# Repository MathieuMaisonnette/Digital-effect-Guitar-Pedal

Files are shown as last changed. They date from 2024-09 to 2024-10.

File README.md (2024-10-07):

# Guitar Effects Pedal - Capacitive Sensor Project

<div align="center">
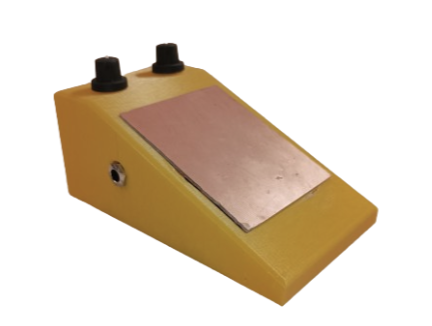
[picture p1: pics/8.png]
finished product
    
</div>

This project focuses on the development of a multi-effects pedal for electric guitars. The pedal integrates a capacitive sensor to manipulate audio effects in real time based on the proximity of the user’s foot to a capacitive plate. This is built using the STM32 microcontroller and includes various iconic guitar effects such as tremolo, fuzz, and overdrive.

**The following explanation is only a summarized version of the project. For more details, feel free to consult the report (in French), which explains the operation of each subcomponent in more detail.**

## Features
- **Capacitive Sensor**: The pedal uses a capacitive plate to adjust effect parameters without physical contact, offering a unique and dynamic user interface.
- **Multi-effects**: The pedal supports a range of effects like fuzz, tremolo, and overdrive, with more effects easily implementable through software updates.
- **STM32 Microcontroller**: A STM32F303-K8 microcontroller is responsible for audio signal processing and handling the effects.
- **Custom PCB and 3D Printed Case**: Designed for compactness and ease of use, the pedal features a custom-printed circuit board (PCB) and a 3D-printed case modeled after well-known pedal designs.

## Hardware Overview
- **Capacitive Sensor**: Detects foot proximity to control effects in real time.

<div align="center">
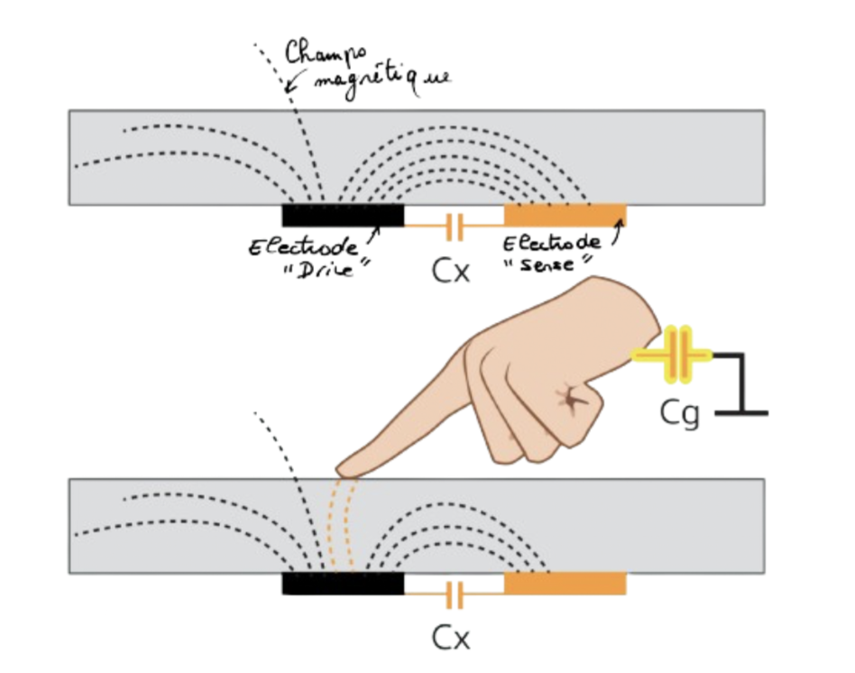
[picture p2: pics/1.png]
    
    <p><em>Figure 1: Operation of the capacitive sensor.</em></p>
</div>

- **STM32F303-K8**: The microcontroller that manages signal processing and control.

<div align="center">
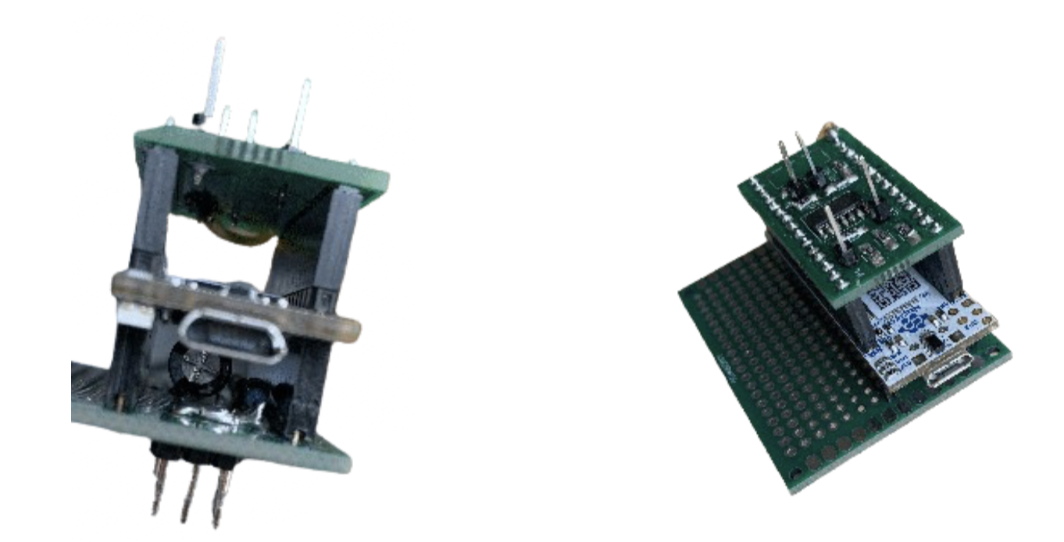
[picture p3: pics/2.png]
Aspect of the conditionner and STM module
    
    <p><em>Figure 2: Aspect of the conditionner and STM module.</em></p>
</div>

- **Effect Selector**: A rotary knob to switch between effects.
- **Parameter Adjuster**: A second knob to fine-tune effect parameters.
- **Connectors**: Standard 6.5mm audio jacks for input/output and a USB connector for power and programming.
- **3D Printed Case**: Designed using Inventor and printed using PrusaSlicer.

## Software
The software is written in C and runs on the STM32 platform, leveraging the HAL library for hardware interactions. The effects are implemented using signal processing techniques such as the Fast Fourier Transform (FFT) and digital filters.

<div align="center">
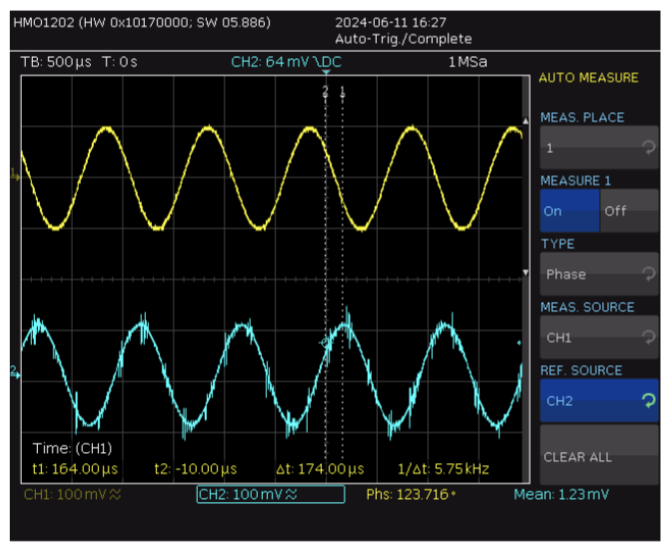
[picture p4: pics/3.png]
Test of the signal loopback on the ADC/DAC. Output signal in yellow
    
    <p><em>Figure 3: Test of the signal loopback on the ADC/DAC. Output signal in yellow.</em></p>
</div>

### Supported Effects
- **Tremolo**: Modulates the volume of the input signal at a user-defined rate.

<div align="center">
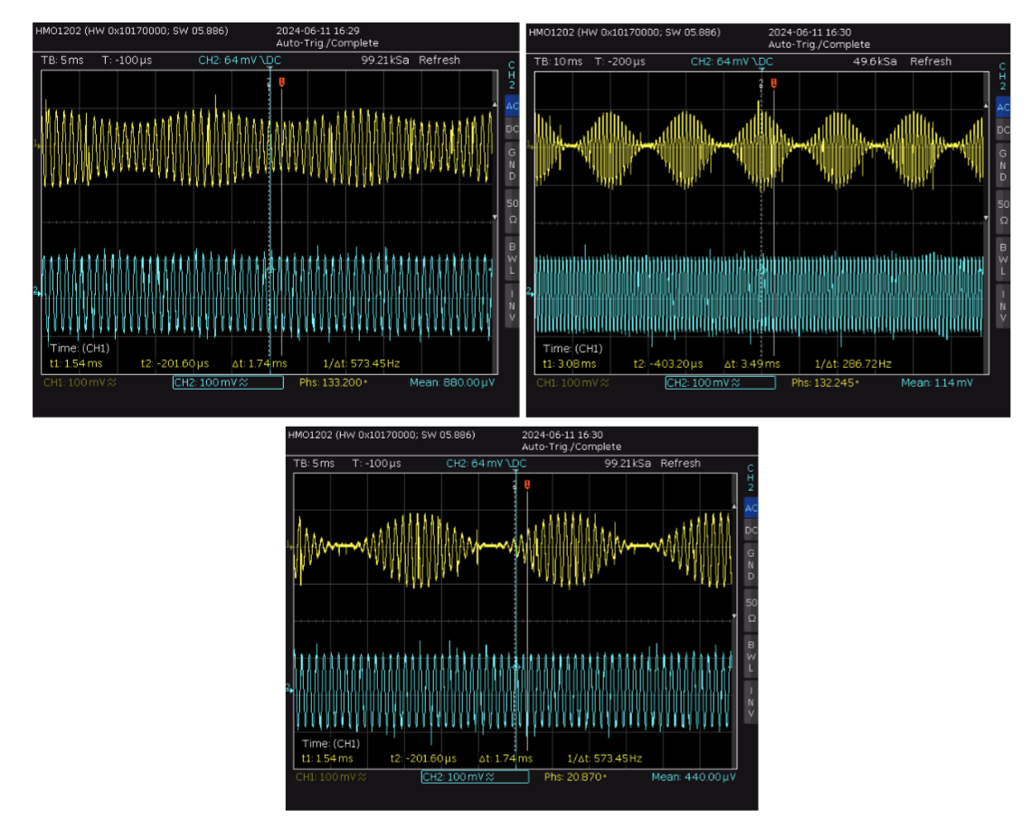
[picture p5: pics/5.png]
Test of the tremolo signal
    
    <p><em>Figure 4: Test of the tremolo signal.</em></p>
</div>

- **Fuzz/Distortion**: Adds harmonic distortion to the signal for a richer, more aggressive tone.

<div align="center">
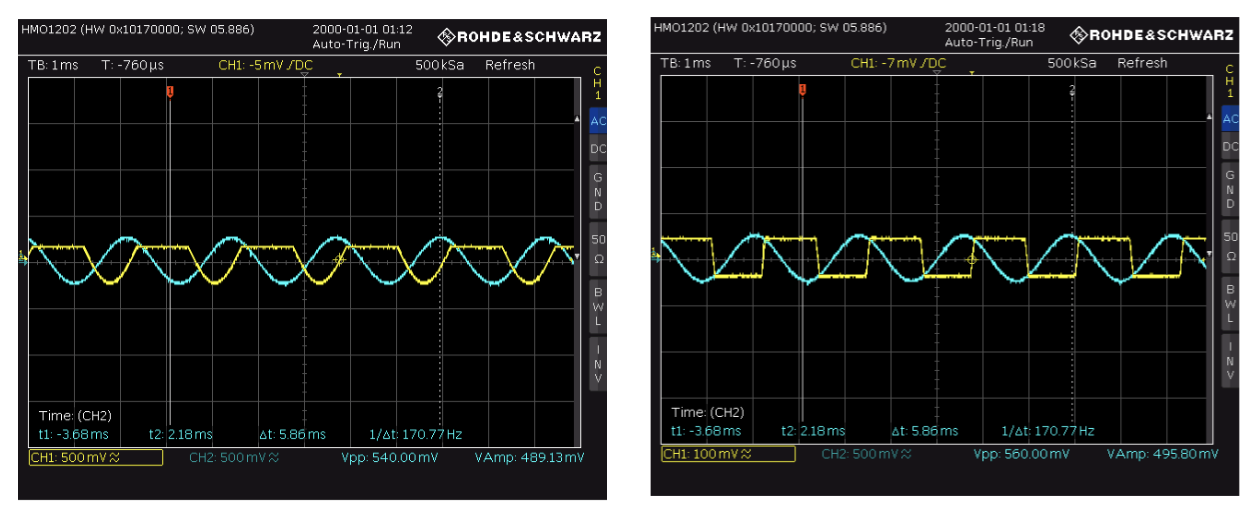
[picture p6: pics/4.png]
Test of the distortion signal
    
    <p><em>Figure 5: Test of the distortion signal.</em></p>
</div>

- **Overdrive**: Currently under development, providing a smoother form of distortion.
- **Wah** : Modulates the tone of an audio signal by sweeping through a range of frequencies. 
  
### Future Improvements
- **Effect Variety**: Additional effects can be implemented by updating the software.
- **LCD Display**: Potential to add an LCD for real-time feedback on the selected effect and parameter settings.
- **Improved Sensor Sensitivity**: Increasing the detection range of the capacitive sensor for finer control.

## How to Use
1. **Connect the Pedal**: Plug your guitar into the input jack and connect the output to an amplifier.
2. **Power On**: Use a USB cable to power the pedal and program the microcontroller.
3. **Select Effects**: Use the left rotary knob to select between available effects.
4. **Adjust Parameters**: Modify the intensity or frequency of the effect using the right knob.
5. **Real-Time Control**: Move your foot above the capacitive plate to dynamically alter the effect parameters.

## Setup and Installation
1. **Download the Code**: Clone the repository from GitHub.
2. **Flash the Microcontroller**: Use an ST-Link or USB to flash the STM32F303 with the provided firmware.
3. **Assemble the Hardware**: Follow the instructions in the hardware folder to assemble the pedal and integrate the components.
4. **Test the Pedal**: After assembly, test the pedal with a guitar and amplifier, adjusting the effects using the knobs and capacitive sensor.

## Files and Directories
- **/src**: Contains the main code for the effects and sensor control.
- **/hardware**: Schematics for the custom PCB and 3D printing files for the case.
- **/docs**: Documentation related to the project design and future improvements.

## Acknowledgments
- Inspiration from classic analog pedals such as wah-wah, fuzz, and tremolo.
- Use of STM32F303-K8 microcontroller for audio processing.
- 3D design tools: Inventor and PrusaSlicer for case design and manufacturing.

<div align="center">
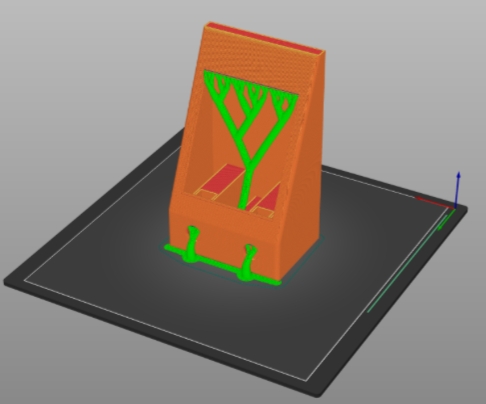
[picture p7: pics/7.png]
    
    <p><em>Figure 6: PrusaSlicer's view of the 3D model.</em></p>
</div>

## Possibilies of improvement 
- Modulate the code to make it cleaner.

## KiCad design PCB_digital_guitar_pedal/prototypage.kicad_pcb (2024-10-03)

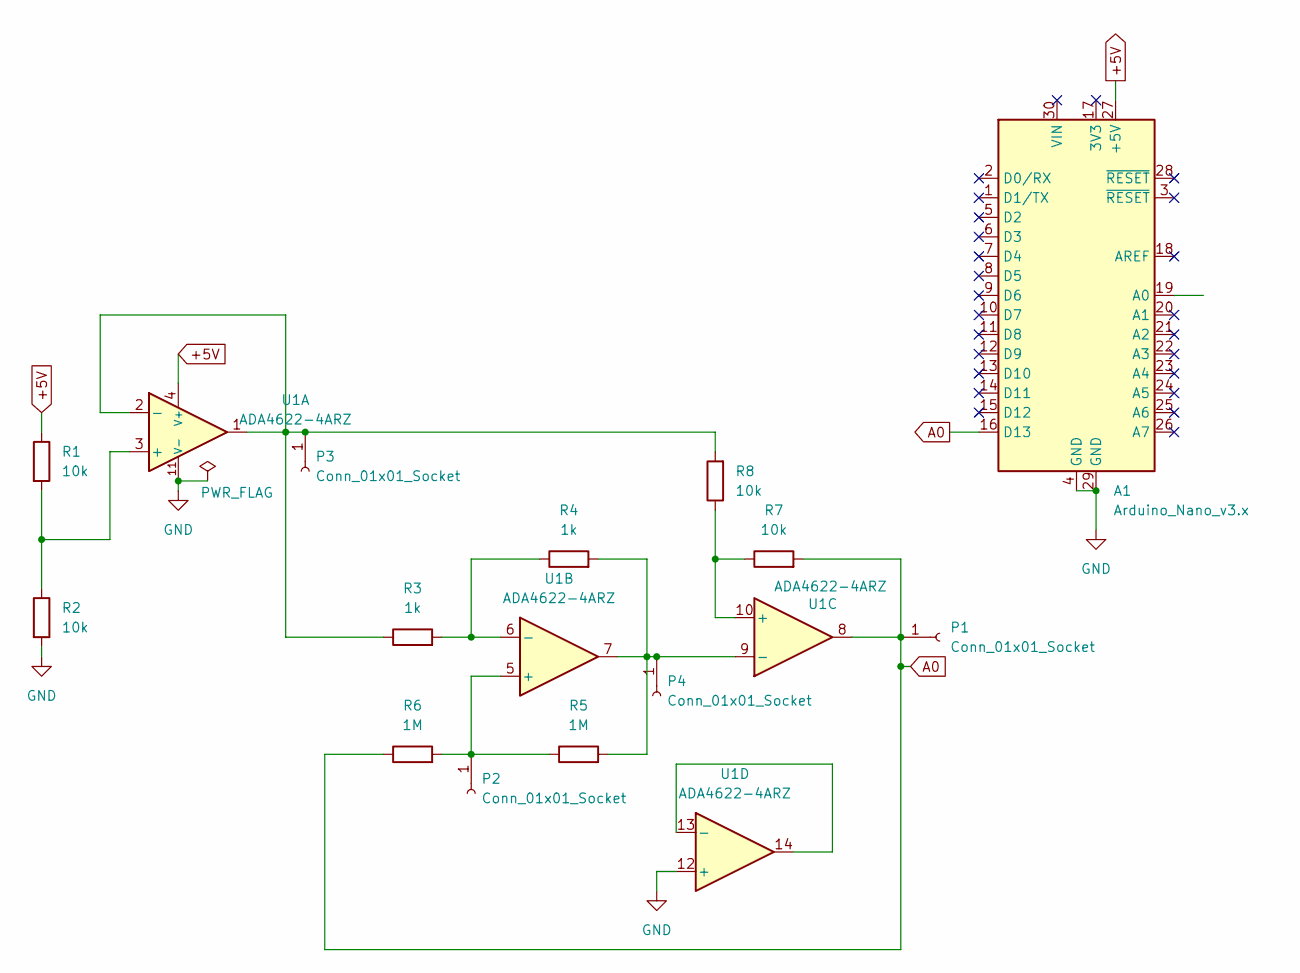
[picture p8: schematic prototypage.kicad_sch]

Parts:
A1: Arduino_Nano_v3.x; Arduino_Nano
P1, P2, P3, P4: Conn_01x01_Socket; PinHeader_1x01_P2.54mm_Vertical
R1, R2, R7, R8: 10k; R_0805_2012Metric_Pad1.20x1.40mm_HandSolder
R3, R4: 1k; R_0805_2012Metric_Pad1.20x1.40mm_HandSolder
R5, R6: 1M; R_0805_2012Metric_Pad1.20x1.40mm_HandSolder
U1: ADA4622-4ARZ; SOIC-14_3.9x8.7mm_P1.27mm

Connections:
+5V: A1.27 (+5V), R1.1, U1.4 (V+)
A0: A1.16 (D13), P1.1, R6.1, R7.2, U1.8
GND: A1.4 (GND), A1.29 (GND), R2.2, U1.11 (V-), U1.12 (+)
unnamed: P2.1, R5.1, R6.2, U1.5 (+)
unnamed: P3.1, R3.1, R8.2, U1.1, U1.2 (-)
unnamed: P4.1, R4.2, R5.2, U1.7, U1.9 (-)
unnamed: R1.2, R2.1, U1.3 (+)
unnamed: R3.2, R4.1, U1.6 (-)
unnamed: R7.1, R8.1, U1.10 (+)
unnamed: U1.13 (-), U1.14

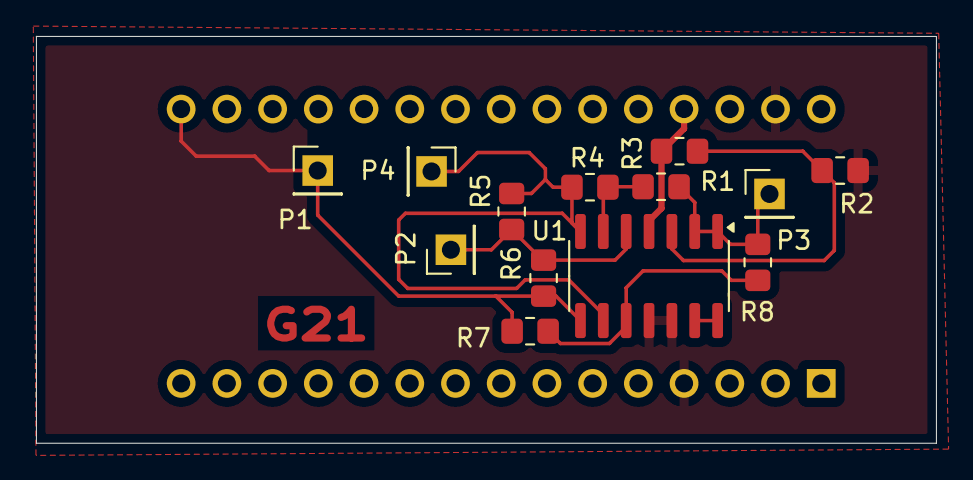
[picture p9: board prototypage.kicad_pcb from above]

Board: 2 copper layers, 50.0 x 22.6 mm, 14 parts (1 on the bottom side), 10 nets.

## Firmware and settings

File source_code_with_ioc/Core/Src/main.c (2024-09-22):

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
/* Includes ------------------------------------------------------------------*/
#include "main.h"

/* USER CODE BEGIN Includes */
#include <math.h>
#include <stdbool.h>
/* USER CODE END Includes */

/* USER CODE BEGIN PTD */

//-----------------------------------------------------------------------------------------------------------*/
// structure de distortion
typedef struct{
	int disto_mode;
	float clipping;
	float gain ;
	float clipping_coef;
}distortion;

//structure flanger
typedef struct{
	int flanger_mode;
	float rate;
	float depth;
	float delay;
    int effect_num;
}flanger;

//structure delay
typedef struct{
    int delay_mode;
    int depth;
    float delay;
    int effect_num;
}delay;

typedef struct{
    int wahwah_mode;
    float rate;
    float depth;
    float minFreq;
    float maxFreq;
    int effect_num;
} wahwah;

typedef struct{
    int tremolo_mode;
    float rate;
    float depth;
    int effect_num;
} tremolo;

typedef struct{
    int vibrato_mode;
    float rate;
    float depth;
    float delay;
    int effect_num;
} vibrato;

/* USER CODE END PTD */

/* USER CODE BEGIN PD */

//define -----------------------------------------------------------------------------------------------------------*/
#define N 500
#define halfN 250
#define NBR_SAMPLES 50
#define OFFSET_SIGNAL 1980//was 1983
#define PI 3.1415

/* USER CODE END PD */

ADC_HandleTypeDef hadc1;
ADC_HandleTypeDef hadc2;
DMA_HandleTypeDef hdma_adc1;
DMA_HandleTypeDef hdma_adc2;

DAC_HandleTypeDef hdac1;
DMA_HandleTypeDef hdma_dac1_ch1;

TIM_HandleTypeDef htim2;
TIM_HandleTypeDef htim6;
TIM_HandleTypeDef htim15;

UART_HandleTypeDef huart2;

/* USER CODE BEGIN PV */
// création des buffers
uint32_t adc_buffer[N];
uint32_t dac_buffer[N];

uint32_t pot_values[N];


int Temps, frequency;
int cnt = 0;

unsigned int t = 0;
int counter_cos = 0, internal_counter_cos = 0;

int ADC_counter = 0;

int pot1;

float test;
//int cos_frequency = 50;

float cos_values[360];
float sin_values[360];
//ADC_ChannelConfTypeDef ADC_config;

volatile uint32_t last_clock = 0;
volatile uint32_t current_clock = 0;
volatile uint8_t i = 0;
volatile uint8_t calcul_open =0;
volatile int difference = 0;
volatile int capacite_pF = 0;
volatile int frequence = 0;
volatile int periode_ns = 0;

//int pot_values[0] = 0, potd_value = 0;
int pot_selector = false;


// initialisation des effets -----------------------------------------------------------------------------------------------------------*/
distortion Disto = {1, 10.0f, 150.0f,1000.0f};
flanger Flanger = {1, 0.5f, 20.0f, 1.0f, 2};
delay Delay = {1, 50, 500.0f, 3};
wahwah Wahwah = {1, 4.0f, 70.0f, 100.0f, 1000.0f, 4};
tremolo Tremolo = {1, 50.0f, 20.0f, 5}; //{1, 5.0f, 50.0f, 5};
vibrato Vibrato = {1, 5.0f, 50.0f, 5.0f, 6};

/* USER CODE END PV */

void SystemClock_Config(void);
static void MX_GPIO_Init(void);
static void MX_DMA_Init(void);
static void MX_USART2_UART_Init(void);
static void MX_TIM2_Init(void);
static void MX_DAC1_Init(void);
static void MX_ADC1_Init(void);
static void MX_TIM15_Init(void);
static void MX_ADC2_Init(void);
static void MX_TIM6_Init(void);
/**
  * @brief  The application entry point.
  * @retval int
  */
int main(void)
{

  /* MCU Configuration--------------------------------------------------------*/

  /* Reset of all peripherals, Initializes the Flash interface and the Systick. */
  HAL_Init();

  /* Configure the system clock */
  SystemClock_Config();

  /* Initialize all configured peripherals */
  MX_GPIO_Init();
  MX_DMA_Init();
  MX_USART2_UART_Init();
  MX_TIM2_Init();
  MX_DAC1_Init();
  MX_ADC1_Init();
  MX_TIM15_Init();
  MX_ADC2_Init();
  MX_TIM6_Init();
  /* USER CODE BEGIN 2 */

  // initialisation de l'effet
  //distortion_init();

  // démarrage des buffers et des timers
  HAL_ADC_Start_DMA(&hadc1, adc_buffer, N);
  HAL_DAC_Start_DMA(&hdac1, DAC_CHANNEL_1, dac_buffer, N, DAC_ALIGN_12B_R);
  //HAL_TIM_Base_Start(&htim2);

  for(int i = 0; i < 360; i++)
  {
	  cos_values[i] = cosf(i*2*PI/360);
	  sin_values[i] = sinf(i*2*PI/360);
  }

  HAL_TIM_Base_Start_IT(&htim15);
  HAL_TIM_IC_Start_IT(&htim2, TIM_CHANNEL_2);
  HAL_TIM_Base_Start_IT(&htim6);




  /* USER CODE END 2 */

  /* Infinite loop */
  /* USER CODE BEGIN WHILE */

  while (1)
  {
	  //HAL_GPIO_TogglePin(TEST1_GPIO_Port, TEST1_Pin);
	  //t += fmodf(cosfrequency*0.002270f, 6.28f);
	  // = cosfrequency*2270;
    /* USER CODE END WHILE */

    /* USER CODE BEGIN 3 */
  }
  /* USER CODE END 3 */
}

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
/* USER CODE BEGIN 4 */

// -------------------------------------------------------------------------------------------------------------------*/
//disto
void distortion_processBuffer(uint32_t* inputData, uint32_t* outputData){

	// si la disto est activée
	if(Disto.disto_mode)
	{
		//float gain = Disto.gain/100;
		//float clipping = Disto.clipping;

		//int16_t high_threshold = 100.0f; //10000.0f - ((clipping/100) * Disto.clipping_coef);
		//int16_t high_threshold = 100 - capacite_pF;
		//int16_t low_threshold = - high_threshold; //1950.0f; // 2900.0f pour amp500mV
		int16_t min_threshold = 20;
		int16_t max_threshold = 50 + (4096 - pot_values[1])*200/4096;//seuil max entre 50 et 250
		int16_t high_threshold = max_threshold - capacite_pF*(max_threshold-min_threshold)/100;
		int16_t low_threshold = - high_threshold; //1950.0f; // 2900.0f pour amp500mV

		for(int i = 0; i < N; i++)
		{
			// get current sample
			int32_t sample = (int32_t)inputData[i];

			int32_t AC_signal = sample - OFFSET_SIGNAL;

			//on applique le gains
			int16_t AC_signal_amplified = (int16_t)((float)AC_signal * (Disto.gain / 100.0f));

			 // clipping
			 if (AC_signal_amplified > high_threshold)
			 {
				 AC_signal_amplified = high_threshold;
			  }
			  else if (AC_signal_amplified < low_threshold) //
			  {
				  AC_signal_amplified = low_threshold;
			  }

			// send to output
			outputData[i] = (int32_t)AC_signal_amplified + OFFSET_SIGNAL;
		}
	}
}

void directloopback_processBuffer(uint32_t* inputData, uint32_t* outputData){
		for(int i = 0; i < N; i++)
		{
			outputData[i] = inputData[i];
		}
}
//flanger--------------------------------------------------------------------------------
/*void flanger_processBuffer(uint32_t* inputData, uint32_t* outputData, int offset){

	if(Flanger.flanger_mode)
	{
		static float phase = 0;

		uint16_t maxDelay  = (Flanger.delay*fe)/1000;
		float lfoFreq = Flanger.rate;
		float lfoDepth = (Flanger.depth/100.0f);

		for(int i = offset; i < offset+halfN; i++)
		{
			// indice courant
			int32_t sample = (int32_t)inputData[i];

			int32_t AC_signal = sample - OFFSET_SIGNAL;

			// delay modulé
			uint16_t delaySamples = (uint16_t)(1+(maxDelay/2)*(1-(lfoDepth * cosf(2*PI*phase)))); //arm_cos_f32 ?

			// indice delay
			int16_t prevSample = (int16_t)inputData[(i + N - delaySamples) % N];

			// envoi sortie
			int16_t AC_transformed = (AC_signal+prevSample)/2;

			outputData[i] = (uint32_t) ( AC_transformed + OFFSET_SIGNAL);

			// maj phase
			phase =  fmodf(phase + lfoFreq / fe,1);
		}
	}
}*/

//delay --------------------------------------------------------------------------------
/*void delay_processBuffer(uint32_t* inputData, uint32_t* outputData, int offset)
{
	uint16_t delaySamples = (Delay.delay*fe)/1000;//fe = 44100
	float feedbackGain = (Delay.depth/100.0f);

	if(Delay.delay_mode)
	{
		for(int i = offset; i < offset +halfN; i++)
		{
			// current sample
			int32_t sample =  (int32_t)inputData[i];

			int32_t AC_signal = sample - OFFSET_SIGNAL;

			// previous sample
			int32_t prevSample = (int32_t)inputData[(i + N - delaySamples) % N];

			// apply feedback gain
			prevSample *= feedbackGain;

            int32_t AC_transformed = (AC_signal + prevSample);

			// mix samples together
			outputData[i] = (uint32_t) (AC_transformed + OFFSET_SIGNAL);
		}
	}
}*/

//tremolo --------------------------------------------------------------------------------
void tremolo_processBuffer(uint32_t* inputData, uint32_t* outputData)
{
	if(Tremolo.tremolo_mode)
	{
		//float phase = 0; // à mettre dans la structure
		float lfoFreq = 1 + (4095.0f - pot_values[1])*100.0f/4096.0f;//Tremolo.rate;
		float lfoDepth = 0.4f + (100.0f-capacite_pF)/200.0f;//(Tremolo.depth/100.0f);
		if(lfoDepth<0.5f)
			lfoDepth = 0.5f;
		//static float phase = 0.0f;
		//float before_sample;
		float sample;//, cosvalue;
		//cosfrequency = lfoFreq;
		for(int i = 0; i < N ; i++) //offset, offset+halfN
		{
			// get current sample
			//float sample = (int32_t)inputData[i];

			// modulate sample volume with lfo
			//sample *= (1.0f-lfoDepth) + lfoDepth * cosf(2.0f*3.14f*t*lfoFreq); //arm_cos_f32 // cosf(2.0f*PI*phase)

			//outputData[i] = sample*(uint32_t)(1.0f-lfoDepth) + lfoDepth * cosf(t) + OFFSET_SIGNAL;
			//outputData[i]
			//counter_cos = fmodf(counter_cos + cosfrequency*0.0000002270f, 6.28f);
			//cosvalue = cosf(counter_cos);
			//float sample = inputData[i];

			//cosvalue = cos_values[counter_cos];
			if(internal_counter_cos >= (int)(1050/lfoFreq))//21 need to be the center, slowest is
			{
				counter_cos++;
				internal_counter_cos = 0;
			}
			internal_counter_cos++;

			//la variable a tendance à passer à une valeur très grande
			if(counter_cos == 360)
				counter_cos = 0;

			sample = ((float)inputData[i] - (float)OFFSET_SIGNAL);
			sample *= ((1.0f-lfoDepth) + lfoDepth * cos_values[counter_cos]);
			//outputData[i] = 50*cosvalue + 1000;//
			outputData[i] = (uint32_t)(sample + OFFSET_SIGNAL);//(uint32_t)(500*cosvalue + 1000);
			//outputData[i] = (uint32_t)(cosvalue*500  + OFFSET_SIGNAL);//(uint32_t)(500*cosvalue + 1000);
			//HAL_GPIO_TogglePin(TEST1_GPIO_Port, TEST1_Pin);
			// update phase
			//t =  fmodf(t + (lfoFreq / ((float)fe)), 3.14f);

		}

	}
}


//vibrato --------------------------------------------------------------------------------

/*void vibrato_processBuffer(uint32_t* inputData, uint32_t* outputData, int offset)
{
	if(Vibrato.vibrato_mode)
	{
		static float phase = 0;
		uint16_t maxDelay  = ((Vibrato.delay)*fe)/1000;
		float lfoFreq = Vibrato.rate;
		float lfoDepth = (Vibrato.depth/100.0f);

		for(int i = offset; i < offset+halfN; i++)
		{
			// get the modulated delay
			uint16_t delaySamples = (uint16_t)(1+(maxDelay/2)*(1-(lfoDepth * cosf(2*PI*phase)))); //arm_cos_f32

			// get the delayed sample
			int16_t prevSample = (int16_t)inputData[(i + N - delaySamples) % N];

			// send to output
			outputData[i] = (uint32_t) prevSample;

			// update phase
			phase =  fmodf(phase + lfoFreq / fe,1);
		}
	}
}*/

//wah wah --------------------------------------------------------------------------------
//coeffs passe bande actuels
static float bp_a0, bp_a1, bp_a2, bp_b0, bp_b1, bp_b2;

// coeffs passe bande précédents
static float bp_x1, bp_x2, bp_y1, bp_y2;

static float currentCutoff = 440.0f; // fréquence de coupure du filtre
static float qFactor = 2.3f; // facteur de qualité du filtre


void new_bandpass()
{
    //int omega_deg = 360.0f*PI * currentCutoff / 44100.0f;//simplif du 2 dans 360/2Pi * 2.0f
    float omega = 2.0f*(float)PI*currentCutoff / 44100.0f;
	float cosomega = (float)cosf((float)omega); //arm_cos_f32
    //float cosomega = (float)cos_values[omega_deg];//reste sinus à faire
    //PROBLEME Vis à vis de cette ligne, le cos fait planter le compteur.
    //Le mieux serait d'utiliser la matrice de cos pour le calculer

   // float cosomega = cos_values[360*omega/(2*PI)] //arm_cos_f32

    //float alpha = sin_values[omega_deg] / (2.0f * qFactor); //arm_sin_f32
	float alpha = (float)sinf((float)omega) / (2.0f * qFactor);

    bp_b0 = alpha;
    bp_b1 = 0;
    bp_b2 = -alpha;
    bp_a0 = 1 + alpha;
    bp_a1 = -2 * cosomega;
    bp_a2 = 1 - alpha;
}

int16_t apply_bandpass(int16_t inSample)
{
    float x0 = (float)inSample;
    float result =
        (bp_b0 / bp_a0) * x0 +
        (bp_b1 / bp_a0) * bp_x1 +
        (bp_b2 / bp_a0) * bp_x2 -
        (bp_a1 / bp_a0) * bp_y1 -
        (bp_a2 / bp_a0) * bp_y2;

    // shift x1 to x2, sample to x1
    // shift y1 to y2, result to y1
    // simulate delay!!
    bp_x2 = bp_x1;
    bp_x1 = x0;
    bp_y2 = bp_y1;
    bp_y1 = result;

    return (int16_t)result;
}

void wahwah_processBuffer(uint32_t* inputData, uint32_t* outputData)
{
	if(Wahwah.wahwah_mode)
	{
		//static float phase = 0;
		//float lfoFreq = Wahwah.rate;
		//float lfoDepth = Wahwah.depth/100.0f;
		float G = (float)(4096 - pot_values[1])*5.0f/4096.0f;//gain entre 0 et 5

		for(int i = 0; i < N; i++)
		{
			// update phase
			//phase = fmodf((phase + lfoFreq / fe), 1);

			// get triangle lfo sample
			//float lfoSample = phase < 0.5 ? phase * 4 - 1 : 3 - 4 * phase;

			// modulate bandpass cutoff
			//currentCutoff = (float)((lfoSample * lfoDepth * centreFreq) + centreFreq);
			currentCutoff = (float)(Wahwah.minFreq + (Wahwah.maxFreq - Wahwah.minFreq)*capacite_pF / 100.0f);//T

			// update bandpass filter
			new_bandpass();

			// get current sample
			int16_t sample = (int16_t) (inputData[i] - OFFSET_SIGNAL);

			// apply bandpass filter to current sample
			sample = apply_bandpass(sample);

			// send to output
			outputData[i] = (uint32_t) ((float)sample*G + OFFSET_SIGNAL);

		}
	}
}



//-----------------------------------------------------------------------------------------------------------------------------*/
// le buffer est à moitié plein
/*void HAL_ADC_ConvHalfCpltCallback(ADC_HandleTypeDef* hadc)
{
	//distortion_processBuffer(adc_buffer, dac_buffer, 0);
	//tremolo_processBuffer(adc_buffer, dac_buffer, 0);

	for( int n=0; n<halfN;n++)
	{
	dac_buffer[n] = adc_buffer[n];	// disto
	}


}*/

// le buffer plein
void HAL_ADC_ConvCpltCallback(ADC_HandleTypeDef* hadc)
{
	if(hadc == &hadc1)
	{
		HAL_GPIO_TogglePin(TEST1_GPIO_Port, TEST1_Pin);
		//distortion_processBuffer(adc_buffer, dac_buffer);
		//wahwah_processBuffer(adc_buffer, dac_buffer);//ATTENTION, bloque le compteur pour le conditionneur
		//tremolo_processBuffer(adc_buffer, dac_buffer);
		//directloopback_processBuffer(adc_buffer, dac_buffer);

		if( pot_values[0] >= 3750)//
		{
			/*for( int n=0; n<N;n++)
			{
				 dac_buffer[n] = adc_buffer[n];

			}*/
			directloopback_processBuffer(adc_buffer, dac_buffer);
		}
		else if(3750 > pot_values[0] && pot_values[0] >= 3295)
		{
			distortion_processBuffer(adc_buffer, dac_buffer);
		}
		else if(3295 > pot_values[0] && pot_values[0] >= 2470)
		{
			tremolo_processBuffer(adc_buffer, dac_buffer);
		}
		else if(2470 >= pot_values[0] && pot_values[0] >= 1700)
		{
			wahwah_processBuffer(adc_buffer, dac_buffer);
		}
		else if(1700 > pot_values[0])
		{
			//autres effets à ajouter ici
			directloopback_processBuffer(adc_buffer, dac_buffer);
		}

	}
	/*if(hadc == &hadc2)
	{
		if(!pot_selector)//first passage
			potd_value = HAL_ADC_GetValue(&hadc2);
		else
			pot_values[0] = HAL_ADC_GetValue(&hadc2);

		pot_selector = !pot_selector;
	}*/

}

int calculate_capacity(int period) {
    // Calcul de la capacité pF en fonction de la période ms
	//int temp_capa = 0.000975619084 * period - 28.122;
	int temp_capa = 0.000975619084 * period - 49;
	if(temp_capa<0)
		temp_capa = 0;
	temp_capa = temp_capa*100 / 240;
	if(temp_capa>100)
			temp_capa = 100;//On mets entre 0 et 100 ici
    return temp_capa ;
}

void HAL_TIM_IC_CaptureCallback(TIM_HandleTypeDef *htim) {
	if(htim == &htim2)
	{
		if(i){
			last_clock = HAL_TIM_ReadCapturedValue(htim, TIM_CHANNEL_2);
			i=0;
		}
		else if(!i){
			current_clock =	HAL_TIM_ReadCapturedValue(htim, TIM_CHANNEL_2);
			difference = current_clock - last_clock;
			if(difference != 0)
				frequence = 32000000/difference;
			else
				return;
			periode_ns = difference*32;
			i=1;
			calcul_open = 1;
		}
		if (calcul_open){
			int temp_capa;
			temp_capa = calculate_capacity(periode_ns);
			if(temp_capa < 500 && temp_capa > -100)
				capacite_pF = temp_capa;
			else
			{
				HAL_GPIO_TogglePin(TEST1_GPIO_Port, TEST1_Pin);
			}
			calcul_open = 0;
		}
	}
}

void HAL_TIM_PeriodElapsedCallback(TIM_HandleTypeDef *htim)
{
	if(htim == &htim6)
	{
		//HAL_ADC_Start_IT(&hadc2);
		  HAL_ADC_Start_DMA(&hadc2, pot_values, 2);
	}
}


/* USER CODE END 4 */
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


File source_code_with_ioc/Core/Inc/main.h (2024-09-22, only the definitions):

#define MCO_Pin GPIO_PIN_0
#define MCO_GPIO_Port GPIOF
#define CONDITIONNEUR_Pin GPIO_PIN_0
#define CONDITIONNEUR_GPIO_Port GPIOA
#define JACK_I_Pin GPIO_PIN_1
#define JACK_I_GPIO_Port GPIOA
#define VCP_TX_Pin GPIO_PIN_2
#define VCP_TX_GPIO_Port GPIOA
#define JACK_O_Pin GPIO_PIN_4
#define JACK_O_GPIO_Port GPIOA
#define POTD_Pin GPIO_PIN_6
#define POTD_GPIO_Port GPIOA
#define POTG_Pin GPIO_PIN_7
#define POTG_GPIO_Port GPIOA
#define SWDIO_Pin GPIO_PIN_13
#define SWDIO_GPIO_Port GPIOA
#define SWCLK_Pin GPIO_PIN_14
#define SWCLK_GPIO_Port GPIOA
#define VCP_RX_Pin GPIO_PIN_15
#define VCP_RX_GPIO_Port GPIOA
#define TEST1_Pin GPIO_PIN_5
#define TEST1_GPIO_Port GPIOB

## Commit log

2024-09-22 July 2024 version of source code with IOC
    The project is working correctly with 4 effects
    [main.c, main.h, pedale_proto_f303.ioc]
2024-10-03 PCB design files added
    [prototypage.kicad_pcb, prototypage.kicad_sch]

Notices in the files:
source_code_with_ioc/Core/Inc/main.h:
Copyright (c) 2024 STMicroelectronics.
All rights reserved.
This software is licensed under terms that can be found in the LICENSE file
